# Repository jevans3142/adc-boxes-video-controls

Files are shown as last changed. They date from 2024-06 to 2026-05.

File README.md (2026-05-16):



# ADC Theatre - Control Boxes Video Switchers

This repository hosts the hardware (in the form of KiCad schematics, PCB layouts, 3D print files, and metalwork cutting outines) and 
firmware (in the form of C code) of the [ADC Theatre's](https://www.adctheatre.com) Control Boxes Video Switchers. These are a pair of control panels mounted in each control box which 
provides remote control of a Blackmagic Design Videohub SDI switcher via Ethernet.

## Features
* Each panel controls a single video output on the switcher, with six sources 
* Panels have steel panel fronts and backs, with a 3D printed case around them
* An additional steel plate mounts the assembly to a VESA mount behind a screen to drop the panel neatly under the screen

## Configuration

Although some things such as number of buttons etc are fixed in hardware, some aspects can be customised via a text file 
on a microSD card read at boot. This provides the ADC with the ability to reconfigure for example which sources are availible on the panel without having to recompile firmware (as long as the physical buttons are relabeled of course!)

Items which can be configured: 
* Which router inputs are used as sources for each of the destinations 
* IP address of the router

## Compilation
The microcontroller used is an ESP32 on an Olimex ESP32-PoE-ISO board. After standard installation of the esp-idf FreeRTOS toolchain, currently building on v5.1.1 as a stable version with the configuration included in the src folder (ie. when building do not run the idf.py set-target esp32 command as directed in the esp-idf Getting Started instructions to set up the default build config - just go straight to idf.py build)

## Hardware
Each panel requires the following components: 
* A Olimex ESP32-PoE-ISO board
* A custom PCB 'main-board' to break out the button/LED connections
* A 3D printed case, which various heat-fit standoffs need to be sunk into to mount the main-board PCB and front/back panels
* A front panel consisting of a laser cut steel panel with buttons/LEDs mounted in; this also has a label strip. A 3D printed version is in the repo, but there is an off-the-shelf part that can be used too 
* A back panel with another 3D printed part used as an SD card cover
* A VESA mounting steel plate 

## Copyright
Copyright (c) 2021-2024 John Evans and contributors.
The ADC Control Boxes Video Switcher hardware and firmware is released under Version 3 of the GNU General Public License.
See the LICENSE file for full details.

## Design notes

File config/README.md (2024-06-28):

# ADC Theatre - Control Boxes Video Switch Panels
## Configuration file format

An example configuration file for the SD card is included in this folder.
Any line beginning with // is regarded as a comment. 
The variable names must not be changed otherwise they will not be recognised. The equals sign also must be present. 

### Routing panel sources/destinations
Controls which source is routed to destination for each button and which output way on the router is used.
Allowed values for sources: 1-40 = sources 1-40 on router
Allowed values for destinations: 1-40 = destinations on router

| Variable name  | Format |
| --- | --- |
| routing_sources | Comma seperated list of numbers |
| routing_destination  | Single number  |

### Router properties

| Variable name  | Format |
| --- | --- |
| router_ip | IP address in x.x.x.x format, no quotes |
| router_port  | Single number  |

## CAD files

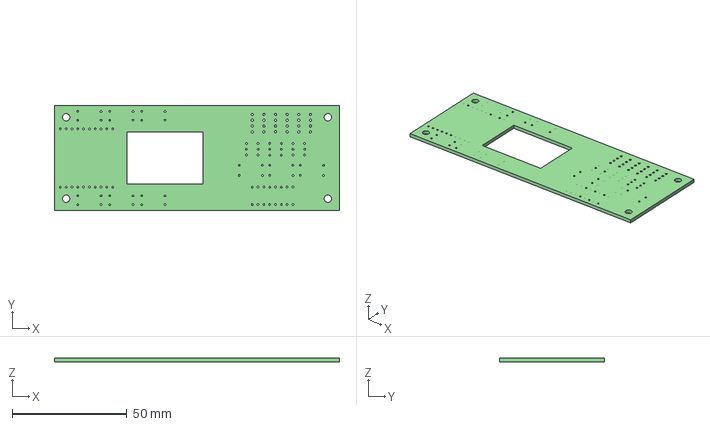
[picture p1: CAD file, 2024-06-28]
hardware/main-board/main-board.step
124.5 x 45.7 x 1.60 mm

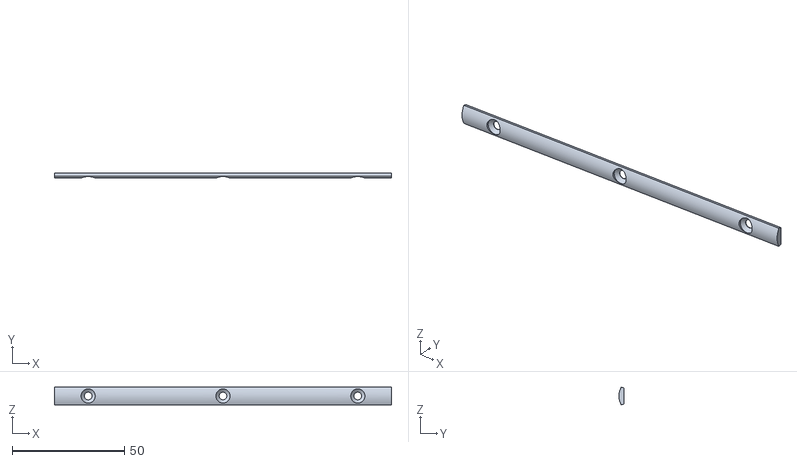
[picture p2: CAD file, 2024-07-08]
hardware/case-etc/LabelStripFinal.stl
150.0 x 2.40 x 7.84

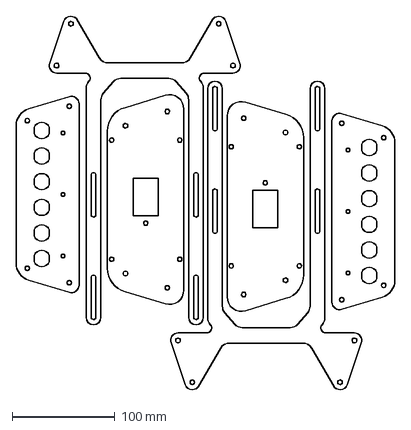
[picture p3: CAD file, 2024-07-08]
hardware/metalwork/Plate_Outlines.dxf
369.7 x 364.6 mm

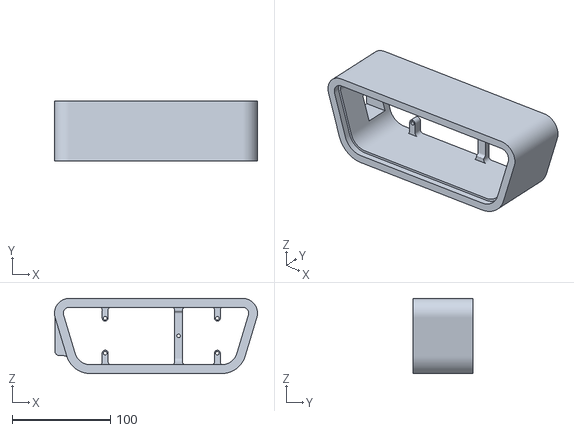
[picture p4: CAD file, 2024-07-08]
hardware/case-etc/Body.stl
206.7 x 61.0 x 76.5

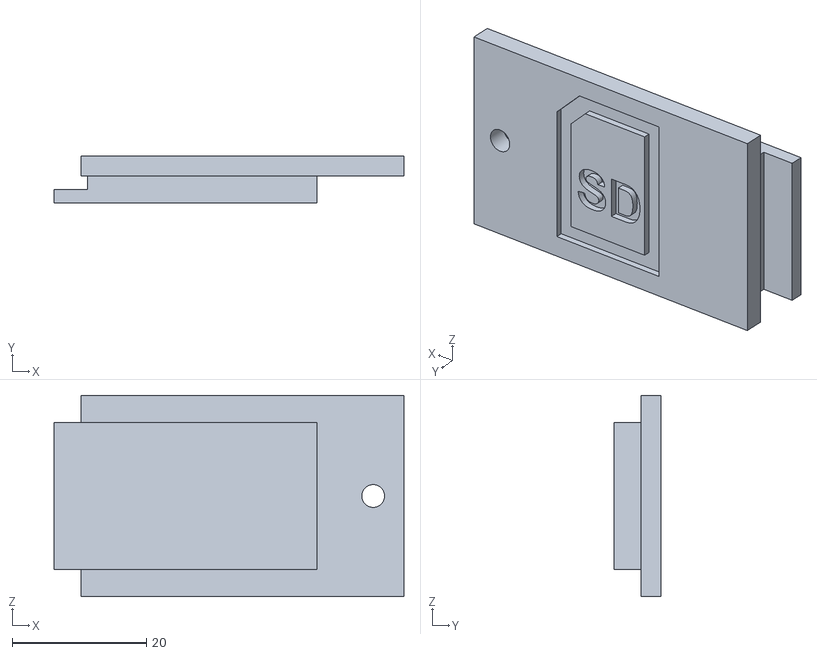
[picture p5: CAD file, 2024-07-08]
hardware/case-etc/SDCardLid.stl
52.2 x 7.00 x 30.0

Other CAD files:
hardware/case-etc/BoxesVideoController.f3z
hardware/metalwork/Plate_Outlines.dwg

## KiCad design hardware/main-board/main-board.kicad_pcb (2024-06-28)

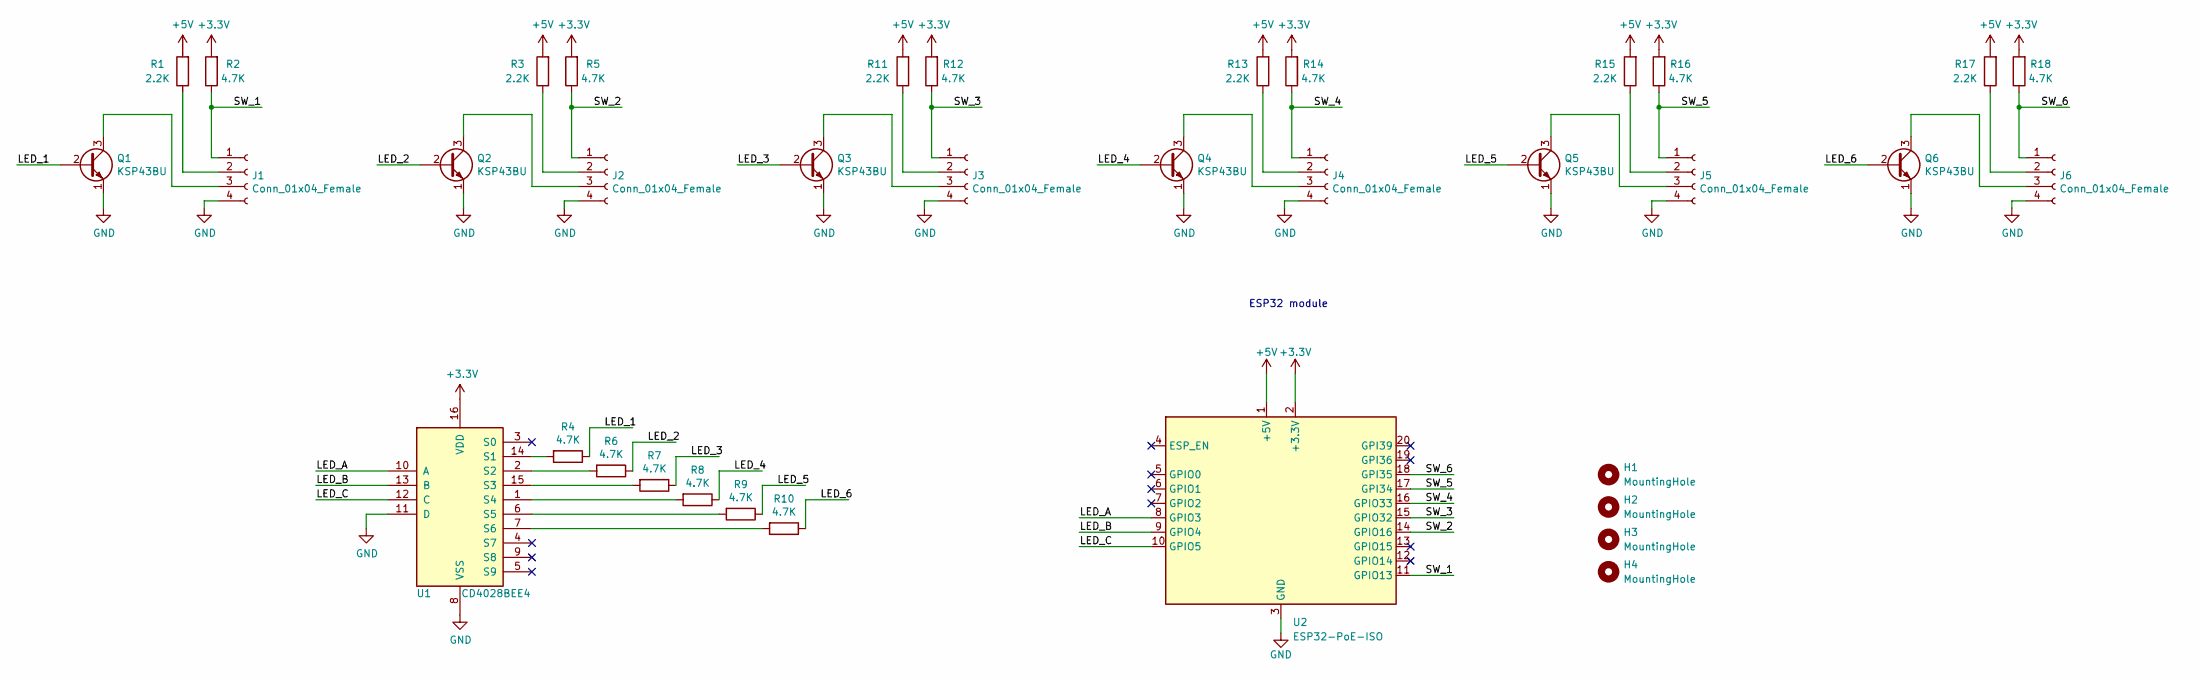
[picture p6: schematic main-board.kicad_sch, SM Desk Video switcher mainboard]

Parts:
H1, H2, H3, H4: MountingHole; MountingHole_3.2mm_M3
J1, J2, J3, J4, J5, J6: Conn_01x04_Female; PinHeader_1x04_P2.54mm_Vertical
Q1, Q2, Q3, Q4, Q5, Q6: KSP43BU; TO-92_Inline_Wide
R1, R3, R11, R13, R15, R17: 2.2K; R_Axial_DIN0207_L6.3mm_D2.5mm_P10.16mm_Horizontal
R2, R4, R5, R6, R7, R8, R9, R10, R12, R14, R16, R18: 4.7K; R_Axial_DIN0207_L6.3mm_D2.5mm_P10.16mm_Horizontal
U1: CD4028BEE4; DIP-16_W7.62mm_Socket
U2: ESP32-PoE-ISO; Olimex_ESP32_PoE_ISO

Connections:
+3V3: R2.2, R5.2, R12.2, R14.2, R16.2, R18.2, U1.16 (VDD), U2.2 (+3.3V)
+5V: R1.2, R3.2, R11.2, R13.2, R15.2, R17.2, U2.1 (+5V)
/LED_1: Q1.2 (B), R4.1
/LED_2: Q2.2 (B), R6.1
/LED_3: Q3.2 (B), R7.1
/LED_4: Q4.2 (B), R8.1
/LED_5: Q5.2 (B), R9.1
/LED_6: Q6.2 (B), R10.1
/LED_A: U1.10 (A), U2.8 (GPIO3)
/LED_B: U1.13 (B), U2.9 (GPIO4)
/LED_C: U1.12 (C), U2.10 (GPIO5)
/SW_1: J1.1, R2.1, U2.11 (GPIO13)
/SW_2: J2.1, R5.1, U2.14 (GPIO16)
/SW_3: J3.1, R12.1, U2.15 (GPIO32)
/SW_4: J4.1, R14.1, U2.16 (GPIO33)
/SW_5: J5.1, R16.1, U2.17 (GPI34)
/SW_6: J6.1, R18.1, U2.18 (GPI35)
GND: J1.4, J2.4, J3.4, J4.4, J5.4, J6.4, Q1.1 (E), Q2.1 (E), Q3.1 (E), Q4.1 (E), Q5.1 (E), Q6.1 (E), U1.8 (VSS), U1.11 (D), U2.3 (GND)
unnamed: J1.2, R1.1
unnamed: J1.3, Q1.3 (C)
unnamed: J2.2, R3.1
unnamed: J2.3, Q2.3 (C)
unnamed: J3.2, R11.1
unnamed: J3.3, Q3.3 (C)
unnamed: J4.2, R13.1
unnamed: J4.3, Q4.3 (C)
unnamed: J5.2, R15.1
unnamed: J5.3, Q5.3 (C)
unnamed: J6.2, R17.1
unnamed: J6.3, Q6.3 (C)
unnamed: R4.2, U1.14 (S1)
unnamed: R6.2, U1.2 (S2)
unnamed: R7.2, U1.15 (S3)
unnamed: R8.2, U1.1 (S4)
unnamed: R9.2, U1.6 (S5)
unnamed: R10.2, U1.7 (S6)

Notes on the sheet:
ESP32 module

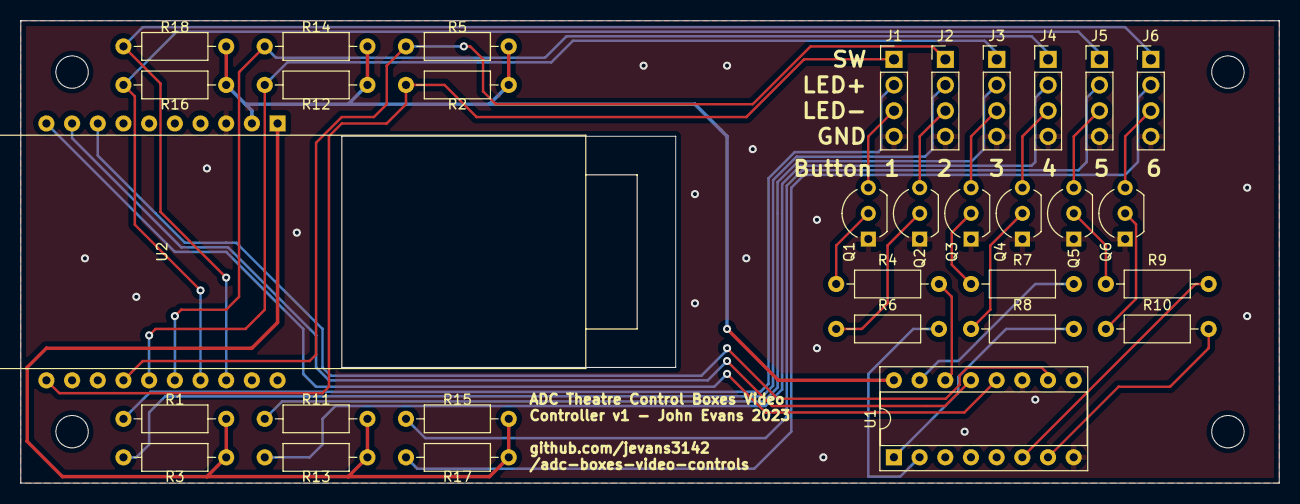
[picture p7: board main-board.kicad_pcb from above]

Board: 2 copper layers, 124.5 x 45.7 mm, 36 parts (0 on the bottom side), 36 nets.

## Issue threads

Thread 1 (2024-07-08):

Indicate when Ethernet link to router is down

jevans3142, 2024-07-08:
When ethernet link goes down, the display of the current route should be wiped from the buttons after a 1 min pause to be replaced with a single blinking light. Obviously as the device is PoE this will only matter for loss of link to the remote end.

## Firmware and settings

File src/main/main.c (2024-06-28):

#include <stdio.h>
#include <string.h>
#include <stdlib.h>
#include "freertos/FreeRTOS.h"
#include "freertos/semphr.h"
#include "freertos/task.h"
#include "esp_err.h"
#include "esp_log.h"
#include "esp_system.h"
#include "nvs_flash.h"
#include "freertos/queue.h" 

#include "main.h"
#include "local_io.h"
#include "ethernet.h"
#include "storage.h"

// Queue handles input to logic from button panels, messages received on ethernet
// Avoids having to poll inputs from main logic (polling, denbouncing, buffering of buttons etc handled in local_io module)
QueueHandle_t input_event_queue; 

// Holds the various settings
// Note that route info is held in 'physical' 1-40 numbering not the 0-39 form - decrements are applied below when commands are sent
struct Settings_Struct settings;

static const char *TAG = "main";

static void input_logic_task(void)
{
    // Task which responds to button presses on the front panel, ethernet messages
    // Uses a queue to respond when required

    while(1)
    {   
        struct Queued_Input_Message_Struct incoming_msg;
        if (xQueueReceive(input_event_queue, &incoming_msg, (TickType_t) portMAX_DELAY) == pdTRUE)
        {
            // Message recieved from queue
            ESP_LOGI(TAG,"Processing message in input logic, type:%i",incoming_msg.type);

            switch (incoming_msg.type)
            {
            case IN_MSG_TYP_ROUTING:
                // Routing input from button panel - send command to switcher
                ESP_LOGI(TAG,"Sending video routing message");
                uint8_t input = settings.routing_sources[incoming_msg.panel_button];
                uint8_t output = settings.routing_destination;

                // Decrement in/outs by 1 to go from physical 1-40 numbering to zero index 
                send_video_route(input - 1, output - 1);

                break;

            case IN_MSG_TYP_ETHERNET:
                // Incoming text message on ethenet
                ESP_LOGI(TAG,"Processing routing confirm message");
                // Work out if the incoming routing confirm applies to any of our screens
                u_int8_t found_button = 0;

                if ((incoming_msg.output + 1) == settings.routing_destination)
                {
                    // It is our screen
                    for (uint8_t button = 0; button<6; button++)
                    {
                        if ((incoming_msg.input + 1) == settings.routing_sources[button])
                        {
                            // and it's one of our outputs 
                            found_button = button + 1; // Got to convert back from zero index to physical button, because 0 = no LED lit
                            break;
                        } 
                    }
                    set_button_led_state(found_button);  
                }

                break;
            default:
                ESP_LOGW(TAG,"Input message unknown:%i",incoming_msg.type);
                break;
            }
            
        }
    }

}

static void local_test_mode(void)
{
    // Vegas mode - LED and button test only
    while (1)
    {
        // Do some dumb polling of the buttons to light any up that are selected

        set_button_led_state(get_button_panel_state());
        vTaskDelay(5);
    
    }
        
}

void app_main(void)
{   
    // Set up input event queue
    input_event_queue = xQueueCreate (32, sizeof(struct Queued_Input_Message_Struct)); 
    if (input_event_queue == NULL)
    {
        ESP_LOGE(TAG,"Unable to create input event queue, rebooting");
        esp_restart();
    }

    // Retrive settings from SD card 
    settings = get_settings();

    //Set up local buttons, LEDs, relay outputs and warning lights
    setup_local_io(&input_event_queue);

    vTaskDelay(10); // Wait to see if buttons are being held down
    //Check to see if we're heading into 'vegas mode' for testing rather than the proper application
    if (get_button_panel_state() == 1)
    {
        local_test_mode();
        return; 
    }

    // Set up ethernet stack and communication with video router
    setup_ethernet(settings.router_ip, settings.router_port, &input_event_queue);

    xTaskCreate( (TaskFunction_t) input_logic_task, "input_logic_task", 2048, NULL, 5, NULL);
}

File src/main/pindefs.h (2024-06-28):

// Pin definitions for IO
//-----------------------------------

#ifndef PINDEFS_H_INCLUDED
#define PINDEFS_H_INCLUDED

// Pin defs

#define PIN_SDCARD_CMD 15
#define PIN_SDCARD_CLK 14
#define PIN_SDCARD_DTA 2

#define PIN_PHY_MDC 23
#define PIN_PHY_MDIO 18
#define PIN_PHY_RST -1
#define PIN_PHY_POWER 12

#define PIN_LED_A 3 
#define PIN_LED_B 4 
#define PIN_LED_C 5 

#define PIN_BUTTON_1 13
#define PIN_BUTTON_2 16
#define PIN_BUTTON_3 32
#define PIN_BUTTON_4 33
#define PIN_BUTTON_5 34
#define PIN_BUTTON_6 35

#define PIN_BUTTON_MASK (1ULL << PIN_BUTTON_1) | (1ULL << PIN_BUTTON_2) | (1ULL << PIN_BUTTON_3) | (1ULL << PIN_BUTTON_4) | (1ULL << PIN_BUTTON_5) | (1ULL << PIN_BUTTON_6)

#define PIN_LED_MASK (1ULL << PIN_LED_A) | (1ULL << PIN_LED_B) | (1ULL << PIN_LED_C)  

#endif

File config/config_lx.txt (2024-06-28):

// Boxes switcher config file - LX Box
// All lines starting // are regarded as comments and are ignored
// Variable names and file format must NOT be changed
// Where multiple numbers are allowed, separate with commas

// Routing sources/destinations
// Controls which source is routed to destination for each button
// Also controls which output way on the router is used
// Allowed values for sources: 1-40 = for sources 1-40 on router
// Allowed values for destination: 1-40 = destinations on router
// ==================

// Button panel 
routing_sources = 33,1,39,6,5,4
routing_destination = 5


// Router properties
// IPv4 Address and port
router_ip = 192.168.11.41
router_port = 9990

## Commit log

2024-06-28 Initial deployment
    Based on SM desk video switcher - initial deployment
    [config_lx.txt, config_snd.txt, main-board.kicad_pcb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]
2024-07-08 Add PCB and 3D printing files
    [Body.stl, BoxesVideoController.f3z, LabelStripFinal.stl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]
